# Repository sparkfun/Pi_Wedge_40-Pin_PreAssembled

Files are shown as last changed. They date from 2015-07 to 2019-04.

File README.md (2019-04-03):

Pi Wedge 40-Pin PreAssembled - Breakout For 40-Pin, Second Generation Raspberry Pi GPIO Connector.
----------------------------

Pi Wedge (https://www.sparkfun.com/products/13717)

[SparkFun Pi Wedge (PreAssembled) [BOB-13717]](https://www.sparkfun.com/products/13717)

This part was created in Eagle v6.5.0.  Software examples were developed using the [WiringPi](wiringpi.com) libraries and utilities.

Repository Contents
-------------------

* **/Hardware** - All Eagle design files (.brd, .sch, .STL)
* **/Software** - C source code for SPI, I2C and GPIO examples.  All use [WiringPi](wiringpi.com) for the underlying device interfaces
* **/Production** - Production panel files (.brd)

Documentation
--------------
* **[Hookup Guide](https://learn.sparkfun.com/tutorials/preassembled-40-pin-pi-wedge-hookup-guide)** - Basic hookup guide for the Pi Wedge.
* **[Raspberry gPIo](https://learn.sparkfun.com/tutorials/raspberry-gpio)** - Programming guide using the Pi's I/O pins with Python and C. 
* **[Raspberry Pi SPI and I2C Tutorial](https://learn.sparkfun.com/tutorials/raspberry-pi-spi-and-i2c-tutorial)** - Programming guide using the Pi's SPI and I2C.
* **[SparkFun Fritzing repo](https://github.com/sparkfun/Fritzing_Parts)** - Fritzing diagrams for SparkFun products.
* **[SparkFun 3D Model repo](https://github.com/sparkfun/3D_Models)** - 3D models of SparkFun products. 
* **[SparkFun Graphical Datasheets](https://github.com/sparkfun/Graphical_Datasheets)** -Graphical Datasheets for various SparkFun products.

License Information
-------------------

This product is _**open source**_! 

Please review the LICENSE.md file for license information. 

If you have any questions or concerns on licensing, please contact techsupport@sparkfun.com.

Distributed as-is; no warranty is given.

- Your friends at SparkFun.

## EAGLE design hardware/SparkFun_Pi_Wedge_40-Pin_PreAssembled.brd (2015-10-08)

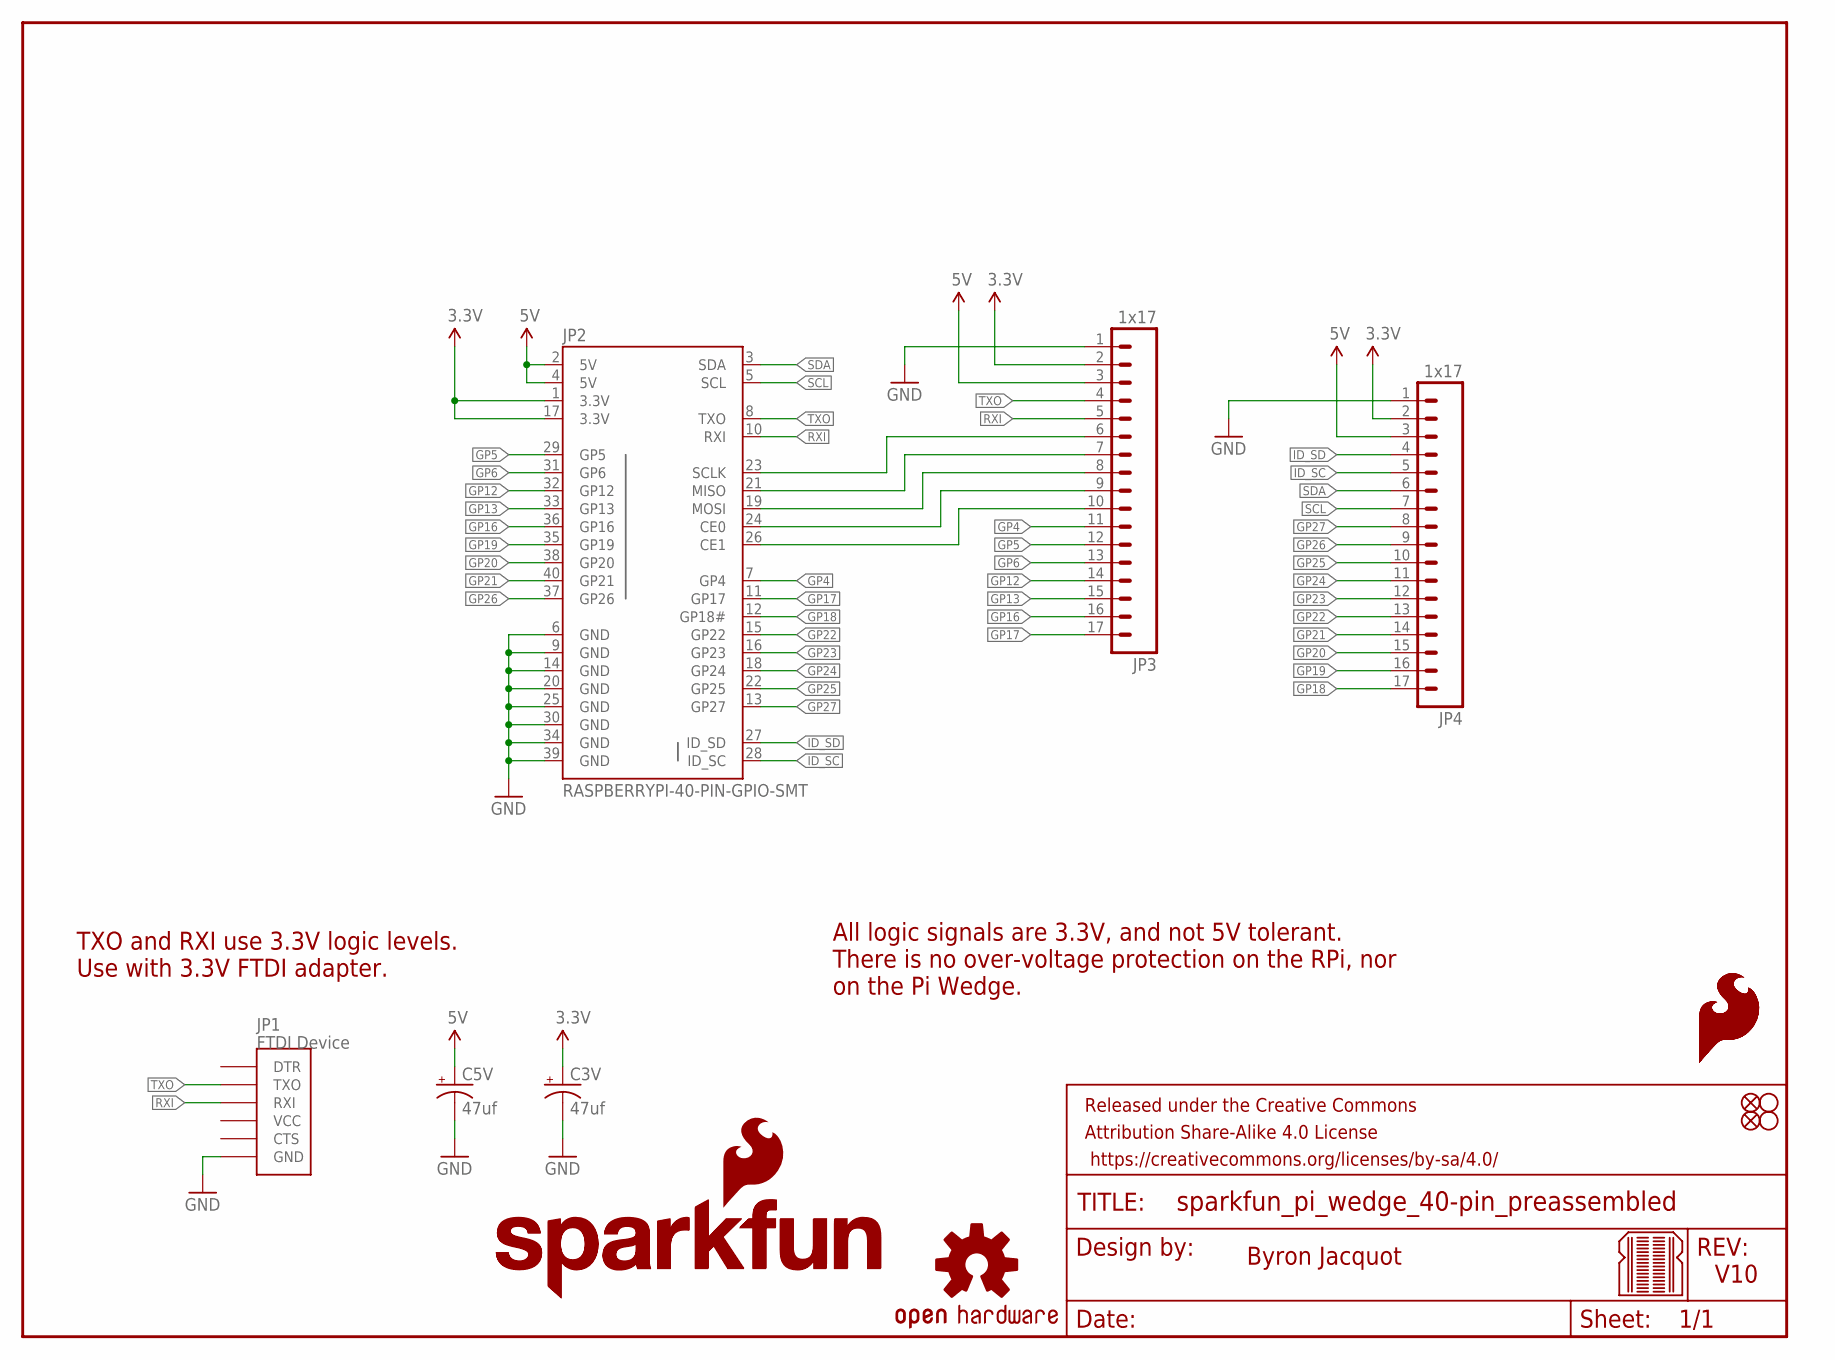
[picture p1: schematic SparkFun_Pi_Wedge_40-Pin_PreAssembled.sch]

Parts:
C3V, C5V: 47uf; PANASONIC_D
FID1, FID2: FIDUCIALUFIDUCIAL; MICRO-FIDUCIAL
FRAME2: FRAME-LETTER; CREATIVE_COMMONS
JP1: FTDI Device; FTDI_DEVICE_RA_SMT
JP2: RASPBERRYPI-40-PIN-GPIO-SMT; 2X20-SHROUDED-SMT
JP3, JP4: 1x17; 1X17_NO_SILK_KIT
LOGO1: SFE_LOGO_NAME.2_INCH; SFE_LOGO_NAME_.2
LOGO2: SFE_LOGO_NAME_FLAME.2_INCH; SFE_LOGO_NAME_FLAME_.2
LOGO3, LOGO4: SFE_LOGO_FLAME.1_INCH; SFE_LOGO_FLAME_.1
LOGO5: OSHW-LOGOS; OSHW-LOGO-S
STANDOFF1, STANDOFF2: STAND-OFF
U$2: BREADBOARD_PATTERN; BREADBOARD_SPACING

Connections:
3.3V: C3V.+, JP2.1 (3.3V), JP2.17 (3.3V), JP3.2, JP4.2
5V: C5V.+, JP2.2 (5V), JP2.4 (5V), JP3.3, JP4.3
CE0: JP2.24 (CE0), JP3.9
CE1: JP2.26 (CE1), JP3.10
GND: C3V.-, C5V.-, JP1.6 (GND), JP2.6 (GND), JP2.9 (GND), JP2.14 (GND), JP2.20 (GND), JP2.25 (GND), JP2.30 (GND), JP2.34 (GND), JP2.39 (GND), JP3.1, JP4.1
GP4: JP2.7 (GP4), JP3.11
GP5: JP2.29 (GP5), JP3.12
GP6: JP2.31 (GP6), JP3.13
GP12: JP2.32 (GP12), JP3.14
GP13: JP2.33 (GP13), JP3.15
GP16: JP2.36 (GP16), JP3.16
GP17: JP2.11 (GP17), JP3.17
GP18: JP2.12 (GP18#), JP4.17
GP19: JP2.35 (GP19), JP4.16
GP20: JP2.38 (GP20), JP4.15
GP21: JP2.40 (GP21), JP4.14
GP22: JP2.15 (GP22), JP4.13
GP23: JP2.16 (GP23), JP4.12
GP24: JP2.18 (GP24), JP4.11
GP25: JP2.22 (GP25), JP4.10
GP26: JP2.37 (GP26), JP4.9
GP27: JP2.13 (GP27), JP4.8
ID_SC: JP2.28 (ID_SC), JP4.5
ID_SD: JP2.27 (ID_SD), JP4.4
MISO: JP2.21 (MISO), JP3.7
MOSI: JP2.19 (MOSI), JP3.8
RXI: JP1.3 (RXI), JP2.10 (RXI), JP3.5
SCL: JP2.5 (SCL), JP4.7
SCLK: JP2.23 (SCLK), JP3.6
SDA: JP2.3 (SDA), JP4.6
TXO: JP1.2 (TXO), JP2.8 (TXO), JP3.4

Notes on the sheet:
Byron Jacquot
V10
All logic signals are 3.3V, and not 5V tolerant. There is no over-voltage protection on the RPi, nor on the Pi Wedge.
TXO and RXI use 3.3V logic levels. Use with 3.3V FTDI adapter.

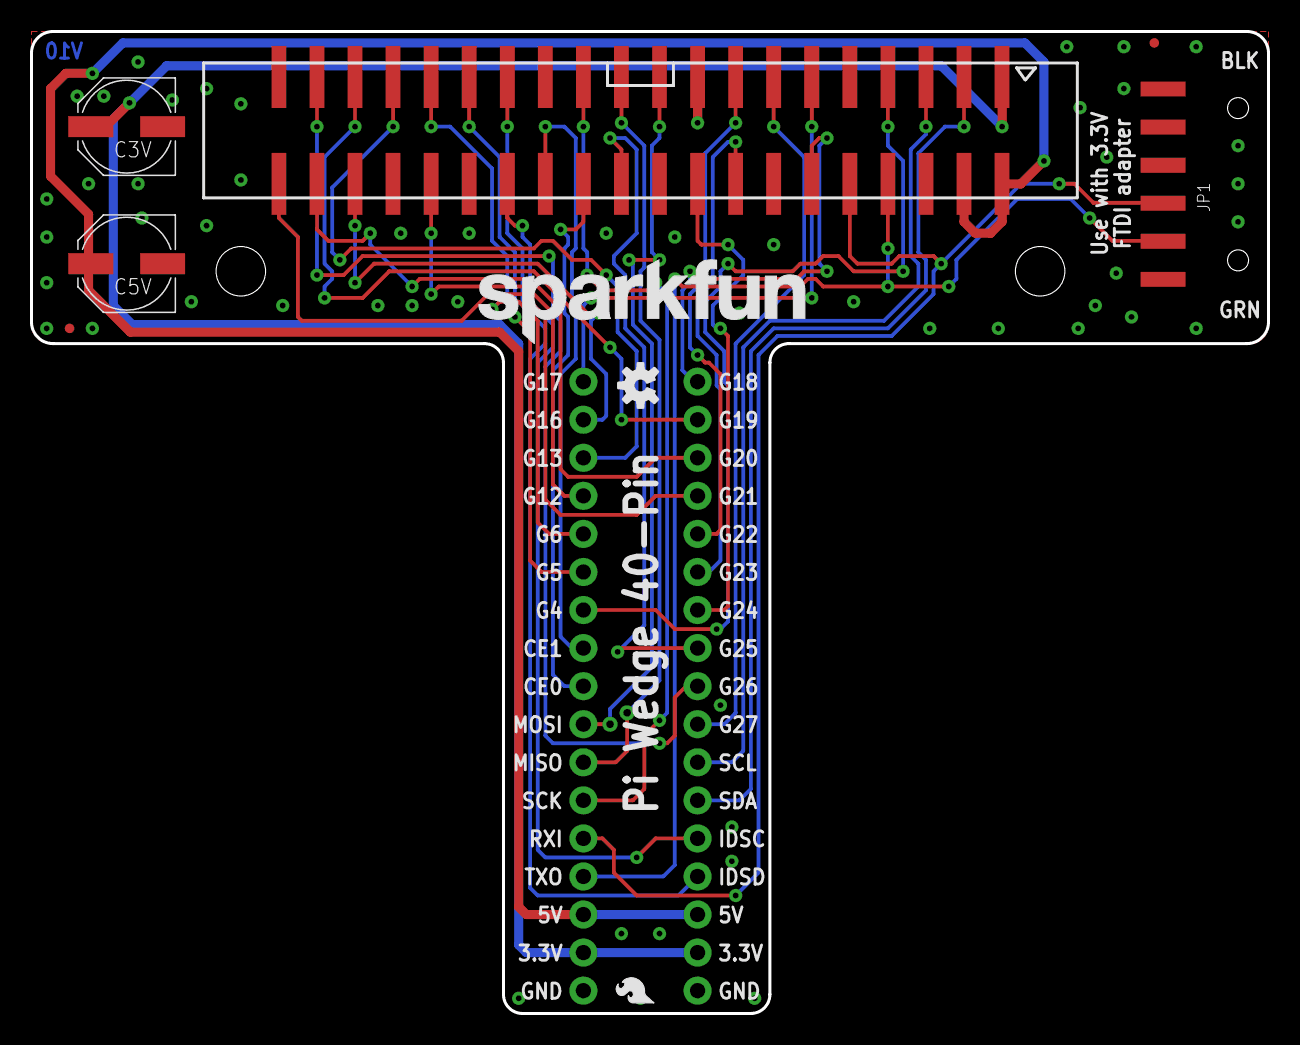
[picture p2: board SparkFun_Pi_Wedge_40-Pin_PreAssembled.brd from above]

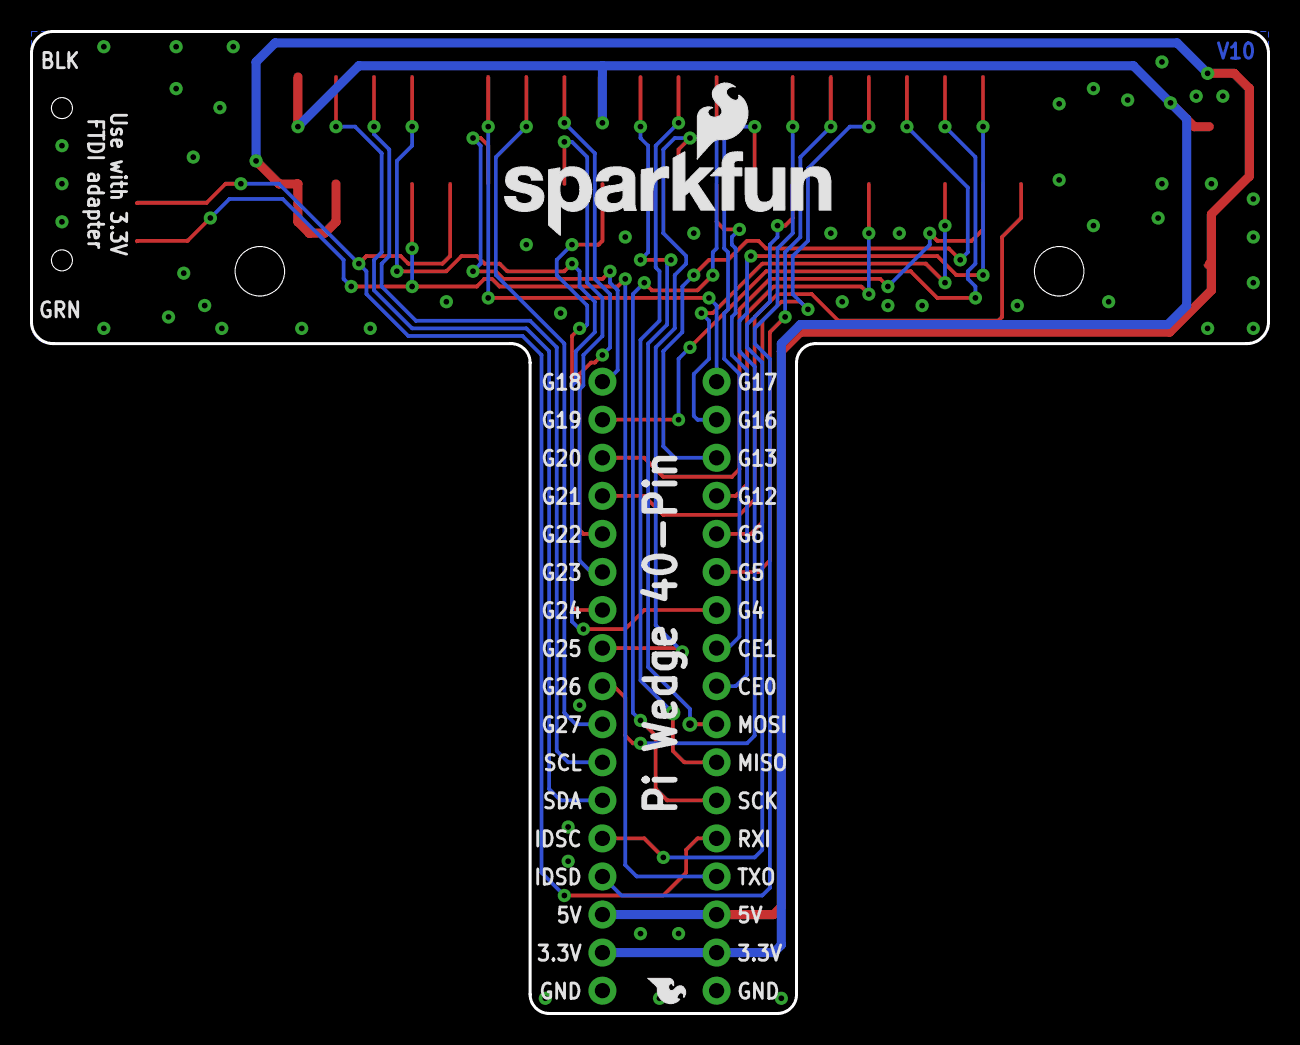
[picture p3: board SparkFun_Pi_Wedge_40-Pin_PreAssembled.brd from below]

Board: 2 copper layers, 82.5 x 65.5 mm, 17 parts (4 on the bottom side), 31 nets.

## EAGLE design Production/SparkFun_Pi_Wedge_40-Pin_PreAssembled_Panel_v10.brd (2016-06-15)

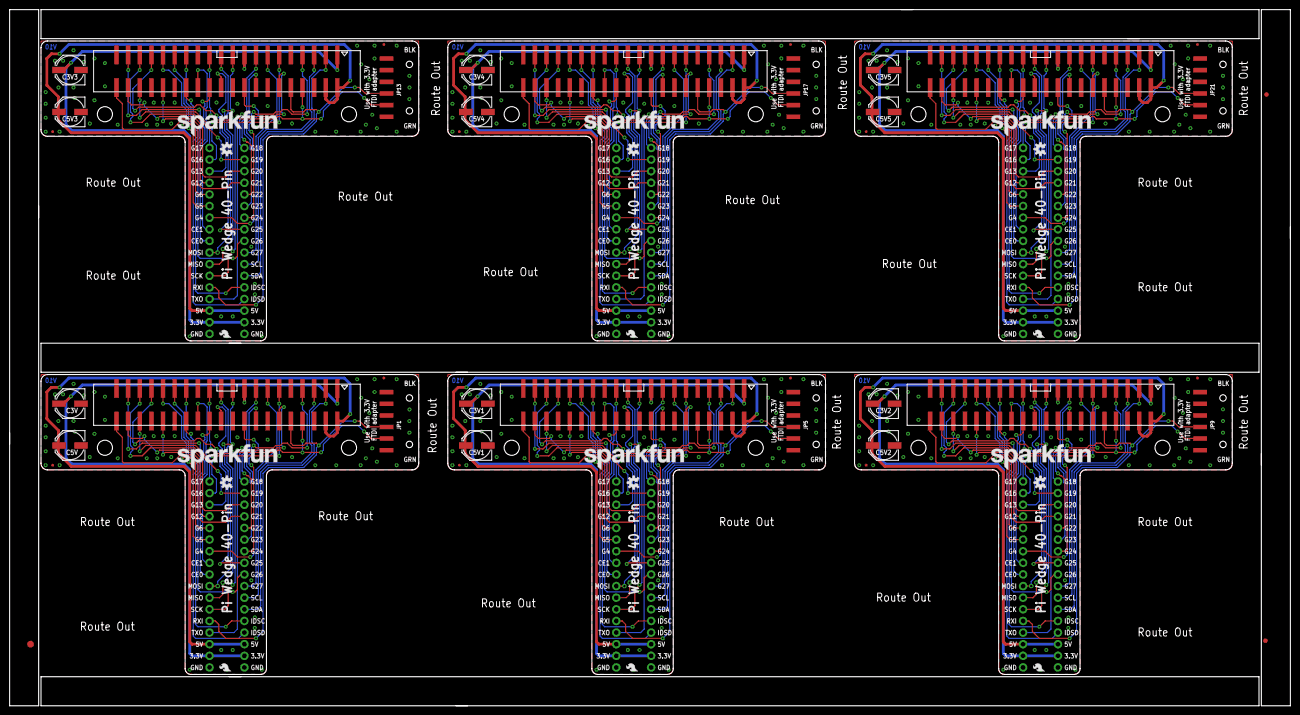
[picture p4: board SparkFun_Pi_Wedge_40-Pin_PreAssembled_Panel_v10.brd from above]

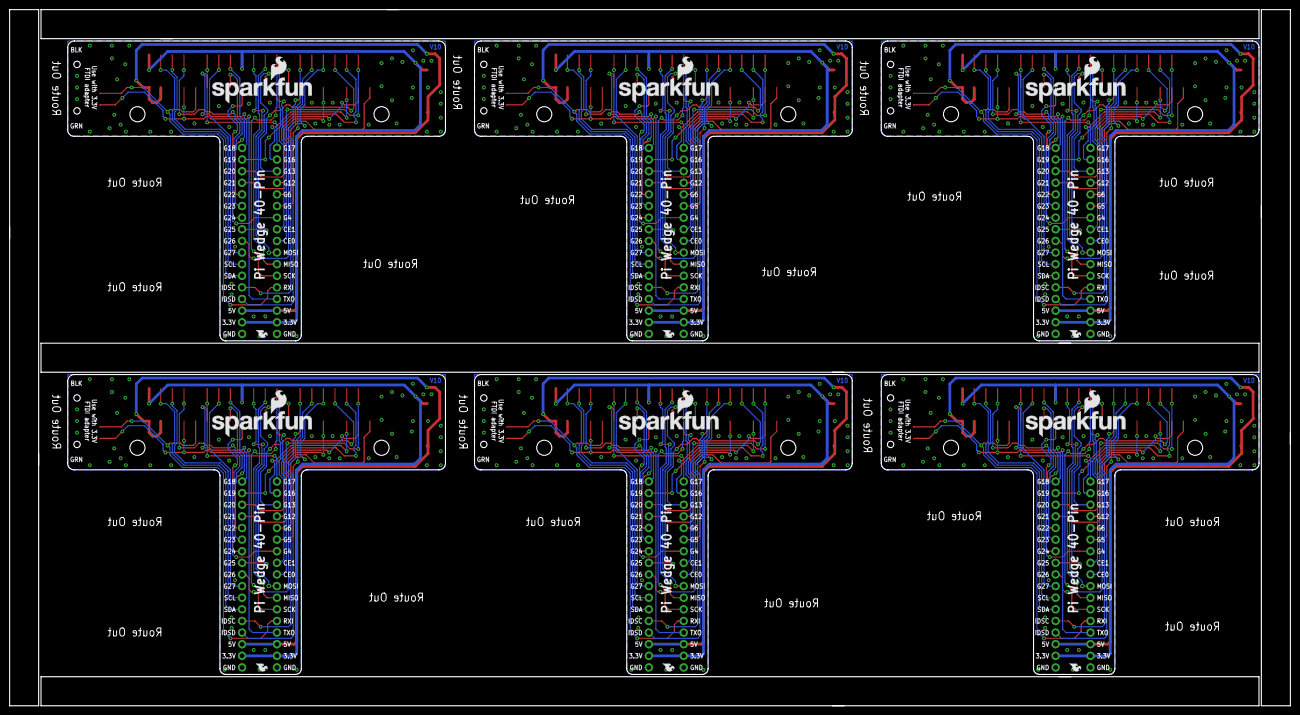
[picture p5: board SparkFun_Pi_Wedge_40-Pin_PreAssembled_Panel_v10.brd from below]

Board: 2 copper layers, 279.9 x 152.1 mm, 93 parts (24 on the bottom side), 186 nets.

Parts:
C3V, C3V1, C3V2, C3V3, C3V4, C3V5, C5V, C5V1, C5V2, C5V3, C5V4, C5V5: 10uf; PANASONIC_D
E$1: FIDUCIAL-1.5X3
E$5, E$6: FIDUCIAL-1X2
FID1, FID2, FID3, FID4, FID5, FID6, FID7, FID8, FID9, FID10, FID11, FID12: FIDUCIALUFIDUCIAL; MICRO-FIDUCIAL
JP1, JP5, JP9, JP13, JP17, JP21: FTDI Device; FTDI_DEVICE_RA_SMT
JP2, JP6, JP10, JP14, JP18, JP22: RASPBERRYPI-40-PIN-GPIO-SMT; 2X20-SHROUDED-SMT
JP3, JP4, JP7, JP8, JP11, JP12, JP15, JP16, JP19, JP20, JP23, JP24: 1x17; 1X17_NO_SILK_KIT
LOGO1, LOGO6, LOGO11, LOGO16, LOGO21, LOGO26: SFE_LOGO_NAME.2_INCH; SFE_LOGO_NAME_.2
LOGO2, LOGO7, LOGO12, LOGO17, LOGO22, LOGO27: SFE_LOGO_NAME_FLAME.2_INCH; SFE_LOGO_NAME_FLAME_.2
LOGO3, LOGO4, LOGO8, LOGO9, LOGO13, LOGO14, LOGO18, LOGO19, LOGO23, LOGO24, LOGO28, LOGO29: SFE_LOGO_FLAME.1_INCH; SFE_LOGO_FLAME_.1
LOGO5, LOGO10, LOGO15, LOGO20, LOGO25, LOGO30: OSHW-LOGOS; OSHW-LOGO-S
STANDOFF1, STANDOFF2, STANDOFF3, STANDOFF4, STANDOFF5, STANDOFF6, STANDOFF7, STANDOFF8, STANDOFF9, STANDOFF10, STANDOFF11, STANDOFF12: STAND-OFF

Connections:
3.3V: C3V.+, JP2.1, JP2.17, JP3.2, JP4.2
3.3V1: C3V1.+, JP6.1, JP6.17, JP7.2, JP8.2
3.3V2: C3V2.+, JP10.1, JP10.17, JP11.2, JP12.2
3.3V3: C3V3.+, JP14.1, JP14.17, JP15.2, JP16.2
3.3V4: C3V4.+, JP18.1, JP18.17, JP19.2, JP20.2
3.3V5: C3V5.+, JP22.1, JP22.17, JP23.2, JP24.2
5V: C5V.+, JP2.2, JP2.4, JP3.3, JP4.3
5V1: C5V1.+, JP6.2, JP6.4, JP7.3, JP8.3
5V2: C5V2.+, JP10.2, JP10.4, JP11.3, JP12.3
5V3: C5V3.+, JP14.2, JP14.4, JP15.3, JP16.3
5V4: C5V4.+, JP18.2, JP18.4, JP19.3, JP20.3
5V5: C5V5.+, JP22.2, JP22.4, JP23.3, JP24.3
CE0: JP2.24, JP3.9
CE1: JP2.26, JP3.10
CE2: JP6.24, JP7.9
CE3: JP6.26, JP7.10
CE4: JP10.24, JP11.9
CE5: JP10.26, JP11.10
CE6: JP14.24, JP15.9
CE7: JP14.26, JP15.10
CE8: JP18.24, JP19.9
CE9: JP18.26, JP19.10
CE10: JP22.24, JP23.9
CE11: JP22.26, JP23.10
GND: C3V.-, C5V.-, JP1.6, JP2.6, JP2.9, JP2.14, JP2.20, JP2.25, JP2.30, JP2.34, JP2.39, JP3.1, JP4.1
GND1: C3V1.-, C5V1.-, JP5.6, JP6.6, JP6.9, JP6.14, JP6.20, JP6.25, JP6.30, JP6.34, JP6.39, JP7.1, JP8.1
GND2: C3V2.-, C5V2.-, JP9.6, JP10.6, JP10.9, JP10.14, JP10.20, JP10.25, JP10.30, JP10.34, JP10.39, JP11.1, JP12.1
GND3: C3V3.-, C5V3.-, JP13.6, JP14.6, JP14.9, JP14.14, JP14.20, JP14.25, JP14.30, JP14.34, JP14.39, JP15.1, JP16.1
GND4: C3V4.-, C5V4.-, JP17.6, JP18.6, JP18.9, JP18.14, JP18.20, JP18.25, JP18.30, JP18.34, JP18.39, JP19.1, JP20.1
GND5: C3V5.-, C5V5.-, JP21.6, JP22.6, JP22.9, JP22.14, JP22.20, JP22.25, JP22.30, JP22.34, JP22.39, JP23.1, JP24.1
GP1: JP6.7, JP7.11
GP2: JP6.13, JP8.8
GP3: JP6.22, JP8.10
GP4: JP2.7, JP3.11
GP5: JP2.29, JP3.12
GP6: JP2.31, JP3.13
GP7: JP6.18, JP8.11
GP8: JP6.16, JP8.12
GP9: JP6.15, JP8.13
GP10: JP6.12, JP8.17
GP11: JP6.11, JP7.17
GP12: JP2.32, JP3.14
GP13: JP2.33, JP3.15
GP14: JP6.29, JP7.12
GP15: JP6.31, JP7.13
GP16: JP2.36, JP3.16
GP17: JP2.11, JP3.17
GP18: JP2.12, JP4.17
GP19: JP2.35, JP4.16
GP20: JP2.38, JP4.15
GP21: JP2.40, JP4.14
GP22: JP2.15, JP4.13
GP23: JP2.16, JP4.12
GP24: JP2.18, JP4.11
GP25: JP2.22, JP4.10
GP26: JP2.37, JP4.9
GP27: JP2.13, JP4.8
GP28: JP6.32, JP7.14
GP29: JP6.33, JP7.15
GP30: JP6.36, JP7.16
GP31: JP6.35, JP8.16
GP32: JP6.38, JP8.15
GP33: JP6.40, JP8.14
GP34: JP6.37, JP8.9
GP35: JP10.7, JP11.11
GP36: JP10.13, JP12.8
GP37: JP10.22, JP12.10
GP38: JP10.18, JP12.11
GP39: JP10.16, JP12.12
GP40: JP10.15, JP12.13
GP41: JP10.12, JP12.17
GP42: JP10.11, JP11.17
GP43: JP10.29, JP11.12
GP44: JP10.31, JP11.13
GP45: JP10.32, JP11.14
GP46: JP10.33, JP11.15
GP47: JP10.36, JP11.16
GP48: JP10.35, JP12.16
GP49: JP10.38, JP12.15
GP50: JP10.40, JP12.14
GP51: JP10.37, JP12.9
GP52: JP14.7, JP15.11
GP53: JP14.13, JP16.8
GP54: JP14.22, JP16.10
GP55: JP14.18, JP16.11
GP56: JP14.16, JP16.12
GP57: JP14.15, JP16.13
GP58: JP14.12, JP16.17
GP59: JP14.11, JP15.17
GP60: JP14.29, JP15.12
GP61: JP14.31, JP15.13
GP62: JP14.32, JP15.14
GP63: JP14.33, JP15.15
GP64: JP14.36, JP15.16
GP65: JP14.35, JP16.16
GP66: JP14.38, JP16.15
GP67: JP14.40, JP16.14
GP68: JP14.37, JP16.9
GP69: JP18.7, JP19.11
GP70: JP18.13, JP20.8
GP71: JP18.22, JP20.10
GP72: JP18.18, JP20.11
GP73: JP18.16, JP20.12
GP74: JP18.15, JP20.13
GP75: JP18.12, JP20.17
GP76: JP18.11, JP19.17
GP77: JP18.29, JP19.12
GP78: JP18.31, JP19.13
GP79: JP18.32, JP19.14
GP80: JP18.33, JP19.15
GP81: JP18.36, JP19.16
GP82: JP18.35, JP20.16
GP83: JP18.38, JP20.15
GP84: JP18.40, JP20.14
GP85: JP18.37, JP20.9
GP86: JP22.7, JP23.11
GP87: JP22.13, JP24.8
GP88: JP22.22, JP24.10
GP89: JP22.18, JP24.11
GP90: JP22.16, JP24.12
GP91: JP22.15, JP24.13
GP92: JP22.12, JP24.17
GP93: JP22.11, JP23.17
GP94: JP22.29, JP23.12
GP95: JP22.31, JP23.13
GP96: JP22.32, JP23.14
GP97: JP22.33, JP23.15
GP98: JP22.36, JP23.16
GP99: JP22.35, JP24.16
GP100: JP22.38, JP24.15
GP101: JP22.40, JP24.14
GP102: JP22.37, JP24.9
ID_SC: JP2.28, JP4.5
ID_SC1: JP6.28, JP8.5
ID_SC2: JP10.28, JP12.5
ID_SC3: JP14.28, JP16.5
ID_SC4: JP18.28, JP20.5
ID_SC5: JP22.28, JP24.5
ID_SD: JP2.27, JP4.4
ID_SD1: JP6.27, JP8.4
ID_SD2: JP10.27, JP12.4
ID_SD3: JP14.27, JP16.4
ID_SD4: JP18.27, JP20.4
ID_SD5: JP22.27, JP24.4
MISO: JP2.21, JP3.7
MISO1: JP6.21, JP7.7
MISO2: JP10.21, JP11.7
MISO3: JP14.21, JP15.7
MISO4: JP18.21, JP19.7
MISO5: JP22.21, JP23.7
MOSI: JP2.19, JP3.8
MOSI1: JP6.19, JP7.8
MOSI2: JP10.19, JP11.8
MOSI3: JP14.19, JP15.8
MOSI4: JP18.19, JP19.8
MOSI5: JP22.19, JP23.8
RXI: JP1.3, JP2.10, JP3.5
RXI1: JP5.3, JP6.10, JP7.5
RXI2: JP9.3, JP10.10, JP11.5
RXI3: JP13.3, JP14.10, JP15.5
RXI4: JP17.3, JP18.10, JP19.5
RXI5: JP21.3, JP22.10, JP23.5
SCL: JP2.5, JP4.7
SCL1: JP6.5, JP8.7
SCL2: JP10.5, JP12.7
SCL3: JP14.5, JP16.7
SCL4: JP18.5, JP20.7
SCL5: JP22.5, JP24.7
SCLK: JP2.23, JP3.6
SCLK1: JP6.23, JP7.6
SCLK2: JP10.23, JP11.6
SCLK3: JP14.23, JP15.6
SCLK4: JP18.23, JP19.6
SCLK5: JP22.23, JP23.6
SDA: JP2.3, JP4.6
SDA1: JP6.3, JP8.6
SDA2: JP10.3, JP12.6
SDA3: JP14.3, JP16.6
SDA4: JP18.3, JP20.6
SDA5: JP22.3, JP24.6
TXO: JP1.2, JP2.8, JP3.4
TXO1: JP5.2, JP6.8, JP7.4
TXO2: JP9.2, JP10.8, JP11.4
TXO3: JP13.2, JP14.8, JP15.4
TXO4: JP17.2, JP18.8, JP19.4
TXO5: JP21.2, JP22.8, JP23.4

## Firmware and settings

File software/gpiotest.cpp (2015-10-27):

/******************************************************************************
gpiotest.cpp
Raspberry Pi GPIO demo
Byron Jacquot @ SparkFun Electronics>
4/2/2014
https://github.com/sparkfun/Pi_Wedge

A brief demonstration of GPIO features on the Raspberry Pi, to demonstrate 
the SparkFun Pi Wedge breakout board.

Resources:

This example makes use of the Wiring Pi library, which streamlines the inteface
the the I/O pins on the Raspberry Pi, providing an API that is similar to the
Arduino.  You can learn about installing Wiring Pi here:
http://wiringpi.com/download-and-install/

The GPIO API is documented here:
https://projects.drogon.net/raspberry-pi/wiringpi/functions/

WiringPi also installs the very useful command-line utility called 'gpio' 
which allows you to configure and query pin status.  Check it's man page for 
more details.

To build this file, I use the command:
>  g++ gpiotest.cpp -lwiringPi

Then to run it, I have to use sudo, as it creates restricted file resources.
> sudo ./a.out

WiringPi defines its own pin numbers, in a contiguous range.  On a B+,
this range is 0 to 31.
You can alternately use the RPi/Broadcom pin numbers.

This test will configure the pins it tests as GPIO outputs.  If you're using
UART, SPI or I2C peripherals, beware that this test will reconfigure those pins.
In particular, it can sever a UART connection.  If you're using a command line
over the serial port, Don't let it hit pins 15 and 16!
If you're using SSH/telnet, you can simply walk from from 0 to 31.

Development environment specifics:
Tested on Raspberry Pi B+ hardware, running Raspbian.
Building with GCC 4.6.3 (Debian 4.6.3-14+rpi1)

This code is beerware; if you see me (or any other SparkFun employee) at the
local, and you've found our code helpful, please buy us a round!

Distributed as-is; no warranty is given.
******************************************************************************/

#include <iostream>
#include <errno.h>
#include <wiringPi.h>

using namespace std;

// This will only touch 0 through 14.  15 and 16 are the UART, which we 
// wouldn't want to reconfigure is you're using them for a terminal.
// If you're using SSH, you can run up to 16.
//static const int FIRST_PIN = 0;
//static const int MAX_PIN = 14;

// For a B+, we also have pins 17 through 31.
// Use these instead, if you want to test the pins above the UART.
static const int FIRST_PIN = 17;
static const int MAX_PIN = 31;

int main()
{
   int result;

   // Init using the wiring Pi numbering scheme ( GPIOs referenced as
   // a contiguous 0 through 16 range).
   //
   // Could alternately call:
   // - wiringPiSetupGpio() to use the native Pi pin numbers
   // - wiringPiSetupSys() to use pre-exported /sys/class/gpio pins.  This
   //                      requires that the pins be pre-exported, but doesn't 
   //                      require root access to run the application.
   result = wiringPiSetup();

   // Result of -1 indicates error
   cout << "Setup result: " << result << endl;

   // set all pins as outputs
   for(int i = FIRST_PIN; i <= MAX_PIN; i++)
   {
      pinMode(i, OUTPUT);

      cout << "init'd pin: " << i << endl;
   }

   // Cycle through the pins, setting one at a time high.
   // Repeat 10 times.
   // This allows us to check them with a meter or oscilloscope.
   for(int i = FIRST_PIN; i <= MAX_PIN; i++)
   {
      for(int j = FIRST_PIN; j <= MAX_PIN; j++)
      {
         if( i  == j)
         {
            cout << "Pin " << j << " set high." <<endl;
            digitalWrite(j, HIGH);
         }
         else
         {
            digitalWrite(j, LOW);
         }
      }

      sleep(1);
   }
}

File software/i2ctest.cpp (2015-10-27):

/******************************************************************************
i2ctest.cpp
Raspberry Pi I2C interface demo
Byron Jacquot @ SparkFun Electronics>
4/2/2014
https://github.com/sparkfun/Pi_Wedge

A brief demonstration of the Raspberry Pi I2C interface, using the SparkFun
Pi Wedge breakout board.

Resources:

This example makes use of the Wiring Pi library, which streamlines the interface
the the I/O pins on the Raspberry Pi, providing an API that is similar to the
Arduino.  You can learn about installing Wiring Pi here:
http://wiringpi.com/download-and-install/

The I2C API is documented here:
https://projects.drogon.net/raspberry-pi/wiringpi/i2c-library/

The init call returns a standard file descriptor.  More detailed configuration
of the interface can be performed using ioctl calls on that descriptor.
See the wiringPi I2C implementation (wiringPi/wiringPiI2C.c) for some examples.
Parameters configurable with ioctl are documented here:
http://git.kernel.org/cgit/linux/kernel/git/torvalds/linux.git/tree/Documentation/i2c/dev-interface

Hardware connections:

This file interfaces with the SparkFun MCP4725 breakout board:
https://www.sparkfun.com/products/8736

The board was connected as follows:
(Raspberry Pi)(MCP4725)
GND  -> GND
3.3V -> Vcc
SCL  -> SCL
SDA  -> SDA

An oscilloscope probe was connected to the analog output pin of the MCP4725.

To build this file, I use the command:
>  g++ i2ctest.cpp -lwiringPi

Then to run it, first the I2C kernel module needs to be loaded.  This can be 
done using the GPIO utility.
> gpio load i2c 400
> ./a.out

This will run the MCP through it's output range several times.  A rising 
sawtooth will be seen on the analog output.

Development environment specifics:
Tested on Raspberry Pi V2 hardware, running Raspbian.
Building with GCC 4.6.3 (Debian 4.6.3-14+rpi1)

This code is beerware; if you see me (or any other SparkFun employee) at the
local, and you've found our code helpful, please buy us a round!

Distributed as-is; no warranty is given.
******************************************************************************/

#include <iostream>
#include <errno.h>
#include <wiringPiI2C.h>

using namespace std;

int main()
{
   int fd, result;

   // Initialize the interface by giving it an external device ID.
   // The MCP4725 defaults to address 0x60.   
   //
   // It returns a standard file descriptor.
   // 
   fd = wiringPiI2CSetup(0x61);

   cout << "Init result: "<< fd << endl;

   for(int i = 0; i < 0x0000ffff; i++)
   {
      // I tried using the "fast write" command, but couldn't get it to work.  
      // It's not entirely obvious what's happening behind the scenes as
      // regards to endianness or length of data sent.  I think it's only 
      // sending one byte, when we really need two.
      //
      // So instead I'm doing a 16 bit register access.  It appears to 
      // properly handle the endianness, and the length is specified by the 
      // call.  The only question was the register address, which is the 
      // concatenation of the command (010x = write DAC output) 
      // and power down (x00x = power up) bits.
      result = wiringPiI2CWriteReg16(fd, 0x40, (i & 0xfff) );
      
      if(result == -1)
      {
         cout << "Error.  Errno is: " << errno << endl;
      }
   }
}

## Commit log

2015-07-30 Initial comit
    Files copied from the PTH Kit version.
    [SparkFun_Pi_Wedge_B_Plus.brd, SparkFun_Pi_Wedge_B_Plus.sch]
2015-07-30 Parts swapped, & old traces ripped up.
    Ready for routing through the narrow neck.
    [SparkFun_Pi_Wedge_B_Plus_PreAssembled.brd, SparkFun_Pi_Wedge_B_Plus_PreAssembled.sch]
2015-07-31 The hard part is routed.
    Ready for Review.
    [SparkFun_Pi_Wedge_B_Plus_PreAssembled.brd]
2015-08-10 A few touch-ups before review.
    [SparkFun_Pi_Wedge_B_Plus_PreAssembled.brd, SparkFun_Pi_Wedge_B_Plus_PreAssembled.sch]
2015-08-11 Added missing PROD_IDs.
    Also apparently picked up huge changes from logo revamp in aesthetics
    library. This commit is huge, but with no physical changes to board or
    schematic.
    [SparkFun_Pi_Wedge_B_Plus_PreAssembled.brd, SparkFun_Pi_Wedge_B_Plus_PreAssembled.sch]
2015-08-13 Fixing review issues.
    [SparkFun_Pi_Wedge_B_Plus_PreAssembled.brd, SparkFun_Pi_Wedge_B_Plus_PreAssembled.sch]
2015-09-21 Updates after group review.
    A few silk touch-ups.
    Renaming to "Pi Wedge 40-Pin".
    [SparkFun_Pi_Wedge_40-Pin_PreAssembled.brd, SparkFun_Pi_Wedge_40-Pin_PreAssembled.sch]
2015-09-22 Updates after checklist review.
    [SparkFun_Pi_Wedge_40-Pin_PreAssembled.brd, SparkFun_Pi_Wedge_40-Pin_PreAssembled.sch]
2015-09-22 created panel v10
    [SparkFun_Pi_Wedge_40-Pin_PreAssembled_Panel_v10.brd]
2015-10-08 Updating caps values.
    It had 47uf library parts (CAP-10547), but the schem incorrectly showed
    10uf as the value.
    Schem now reads 47uf.
    [SparkFun_Pi_Wedge_40-Pin_PreAssembled.brd, SparkFun_Pi_Wedge_40-Pin_PreAssembled.sch]
2016-06-15 increased paste layer on 40-pin connector
    [SparkFun_Pi_Wedge_40-Pin_PreAssembled_Panel_v10.brd]

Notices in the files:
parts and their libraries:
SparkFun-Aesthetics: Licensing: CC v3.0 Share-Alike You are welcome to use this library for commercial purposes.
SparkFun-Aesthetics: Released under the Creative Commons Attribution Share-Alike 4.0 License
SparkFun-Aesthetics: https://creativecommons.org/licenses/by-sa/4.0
